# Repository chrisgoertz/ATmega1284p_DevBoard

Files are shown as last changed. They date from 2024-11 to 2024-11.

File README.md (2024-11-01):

# ATmega1284p_DevBoard
AVR Developement Board
## Features
### LCD Connector
Precofigured Header for standard Character Display pinouts.
### Buttons
8 on board push buttons. 4 with attached pull-up resistor, 4 with
attached pull-down resistor.
### FTDI Connector
Standard FTDI Connector with attachable DTR enable like Arduino. 
So it is possible to reset and programm the MCU via FTDI connection
if a bootloader is flashed and enabled.
### JTAG Connector
2 AVR JTAG Headers for programming and debugging.
### ISP
Standard 6-pin AVR ISP.
### Serial
6-pin connector with UART0 and UART1 and also VCC and GND.
### I²C
6-Pin Connector with SDA and SCL, VCC, GND and GPIO D7.
### LED-BARs
2 10-Channel LED-Bars, attached to PortA and PortC. 
Both channels can be separate enabled by jumper. Since all
LEDs are decoupled via MOSFETs, they don't affect the GPIOs.

## Pictures
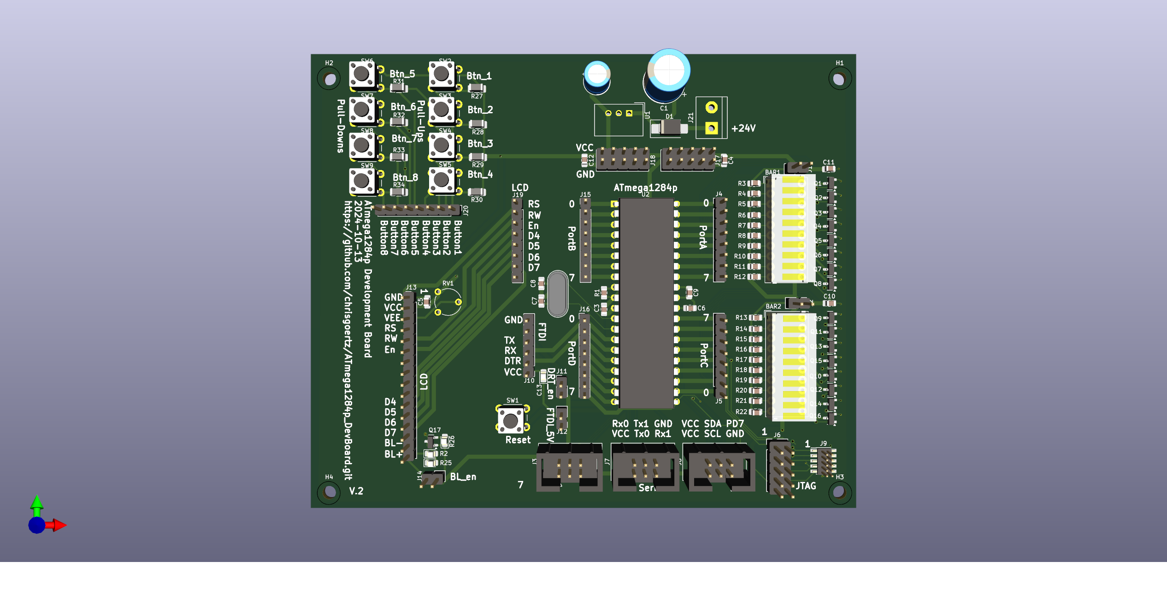
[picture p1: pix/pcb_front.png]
front view

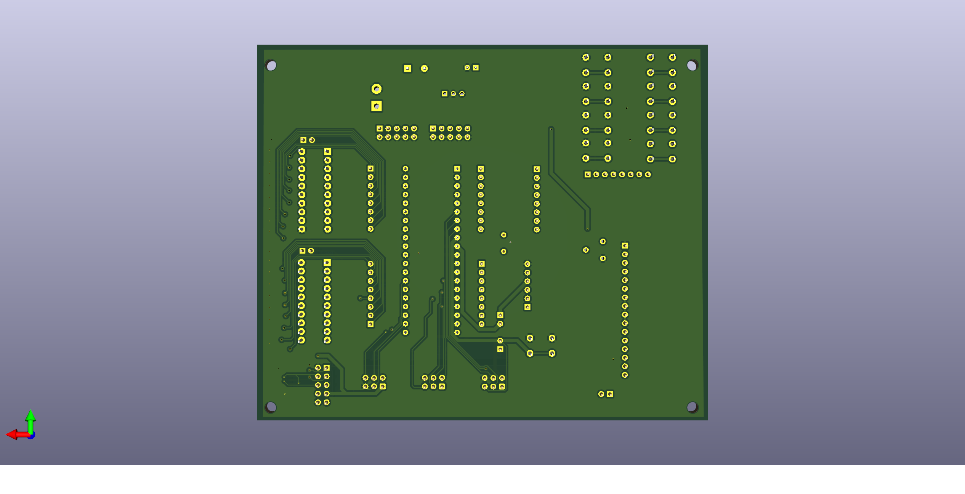
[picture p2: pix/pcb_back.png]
back view


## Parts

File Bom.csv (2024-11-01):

ID | Bezeichner | Footprint | Stückzahl | Bezeichnung | Anbieter und Referenz
1 | SW2,SW5,SW1,SW6,SW3,SW7,SW8,SW9,SW4 | SW_PUSH_6mm | 9 | SW_Push_Open_Dual
2 | J12 | PinHeader_1x02_P2.54mm_Vertical | 1 | FTDI_DTR_en
3 | Q7,Q8,Q2,Q1,Q4,Q11,Q14,Q16,Q6,Q13,Q12,Q9,Q5,Q10,Q17,Q3,Q15 | SOT-23 | 17 | 2N7002
4 | R24,R23 | L_1206_3216Metric_Pad1.42x1.75mm_HandSolder | 2 | 6K19
5 | R29,R32,R33,R34,R28,R31,R30,R27 | L_1206_3216Metric_Pad1.42x1.75mm_HandSolder | 8 | 9K53
6 | R11,R20,R21,R15,R17,R14,R10,R8,R18,R4,R7,R16,R9,R6,R19,R22,R3,R13,R5 | C_0805_2012Metric_Pad1.18x1.45mm_HandSolder | 19 | 330
7 | J17,J18 | PinHeader_2x05_P2.54mm_Vertical | 2 | Supply
8 | R1 | C_0805_2012Metric_Pad1.18x1.45mm_HandSolder | 1 | 11K3
9 | J20 | PinHeader_1x08_P2.54mm_Vertical | 1 | Buttons
10 | R26 | LED_0805_2012Metric_Pad1.15x1.40mm_HandSolder | 1 | 11K3
11 | BAR1,BAR2 | HDSP-4850 | 2 | HDSP-4850_2
12 | J21 | TerminalBlock_bornier-2_P5.08mm | 1 | Power Supply
13 | J9 | PinHeader_2x05_P1.27mm_Vertical_SMD | 1 | AVR-JTAG-10
14 | C11,C4,C9,C10,C3,C6,C12,C5 | C_0805_2012Metric_Pad1.18x1.45mm_HandSolder | 8 | 100nF
15 | C8,C7 | C_0805_2012Metric_Pad1.18x1.45mm_HandSolder | 2 | 22pF
16 | J5 | PinHeader_1x08_P2.54mm_Vertical | 1 | PORTC
17 | R25,R2 | LED_0805_2012Metric_Pad1.15x1.40mm_HandSolder | 2 | 100R
18 | J6 | PinHeader_2x05_P2.54mm_Vertical | 1 | AVR-JTAG-10
19 | C1 | CP_Radial_D10.0mm_P5.00mm | 1 | 470uF
20 | RV1 | Potentiometer_Piher_PT-6-V_Vertical | 1 | 10K
21 | J10 | PinHeader_1x06_P2.54mm_Vertical | 1 | FTDI
22 | J13 | PinHeader_1x16_P2.54mm_Vertical | 1 | LCD
23 | C13 | LED_0805_2012Metric_Pad1.15x1.40mm_HandSolder | 1 | 100nF
24 | J4 | PinHeader_1x08_P2.54mm_Vertical | 1 | PORTA
25 | C2 | CP_Radial_D6.3mm_P2.50mm | 1 | 220uF
26 | J19 | PinHeader_1x08_P2.54mm_Vertical | 1 | LCD_Interface
27 | J2 | PinHeader_1x02_P2.54mm_Vertical | 1 | PortB_LEDS_en
28 | U2 | DIP-40_W15.24mm | 1 | ATmega644-20P
29 | J3 | IDC-Header_2x03_P2.54mm_Vertical | 1 | AVR-ISP-6
30 | J7 | IDC-Header_2x03_P2.54mm_Vertical | 1 | Serial
31 | Y1 | Crystal_HC49-4H_Vertical | 1 | 20 MHz
32 | J8 | IDC-Header_2x03_P2.54mm_Vertical | 1 | I2C
33 | J14 | PinHeader_1x02_P2.54mm_Vertical | 1 | Conn_01x02
34 | U1 | Converter_DCDC_TRACO_TSR1-xxxxE_THT | 1 | TSR1-2450E
35 | J1 | PinHeader_1x02_P2.54mm_Vertical | 1 | PortA_LEDS_en
36 | D1 | D_SMB_Handsoldering | 1 | SMS140
37 | J15 | PinHeader_1x08_P2.54mm_Vertical | 1 | PORTB
38 | R12 | C_0805_2012Metric_Pad1.18x1.45mm_HandSolder | 1 | 930
39 | J11 | PinHeader_1x02_P2.54mm_Vertical | 1 | FTDI_VCC_en
40 | J16 | PinHeader_1x08_P2.54mm_Vertical | 1 | PORTD

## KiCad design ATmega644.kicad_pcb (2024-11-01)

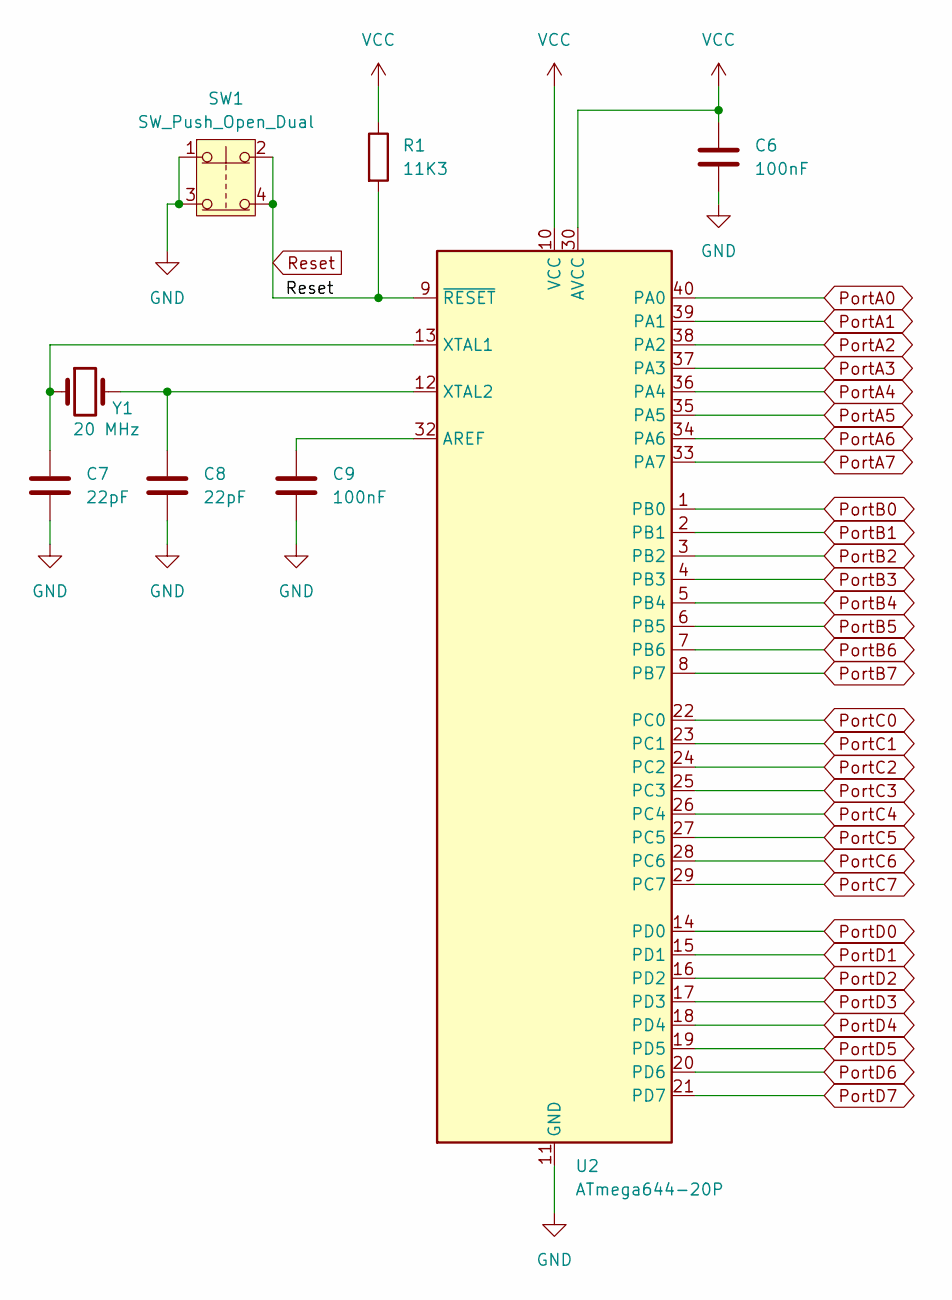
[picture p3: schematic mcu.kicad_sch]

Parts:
C6, C9: 100nF; C_0805_2012Metric_Pad1.18x1.45mm_HandSolder
C7, C8: 22pF; C_0805_2012Metric_Pad1.18x1.45mm_HandSolder
R1: 11K3; C_0805_2012Metric_Pad1.18x1.45mm_HandSolder
SW1: SW_Push_Open_Dual; SW_PUSH_6mm
U2: ATmega644-20P; DIP-40_W15.24mm
Y1: 20 MHz; Crystal_HC49-4H_Vertical

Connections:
GND: C6.2, C7.2, C8.2, C9.2, SW1.1, SW1.3, U2.11 (GND), U2.31 (GND); also elsewhere on the board
unnamed: C9.1, U2.32 (AREF)
unnamed: C7.1, U2.13 (XTAL1), Y1.1
unnamed: C8.1, U2.12 (XTAL2), Y1.2
PortA0: U2.40 (PA0); also elsewhere on the board
PortA1: U2.39 (PA1); also elsewhere on the board
PortA2: U2.38 (PA2); also elsewhere on the board
PortA3: U2.37 (PA3); also elsewhere on the board
PortA4: U2.36 (PA4); also elsewhere on the board
PortA5: U2.35 (PA5); also elsewhere on the board
PortA6: U2.34 (PA6); also elsewhere on the board
PortA7: U2.33 (PA7); also elsewhere on the board
PortB0: U2.1 (PB0); also elsewhere on the board
PortB1: U2.2 (PB1); also elsewhere on the board
PortB2: U2.3 (PB2); also elsewhere on the board
PortB3: U2.4 (PB3); also elsewhere on the board
PortB4: U2.5 (PB4); also elsewhere on the board
PortB5: U2.6 (PB5); also elsewhere on the board
PortB6: U2.7 (PB6); also elsewhere on the board
PortB7: U2.8 (PB7); also elsewhere on the board
PortC0: U2.22 (PC0); also elsewhere on the board
PortC1: U2.23 (PC1); also elsewhere on the board
PortC2: U2.24 (PC2); also elsewhere on the board
PortC3: U2.25 (PC3); also elsewhere on the board
PortC4: U2.26 (PC4); also elsewhere on the board
PortC5: U2.27 (PC5); also elsewhere on the board
PortC6: U2.28 (PC6); also elsewhere on the board
PortC7: U2.29 (PC7); also elsewhere on the board
PortD0: U2.14 (PD0); also elsewhere on the board
PortD1: U2.15 (PD1); also elsewhere on the board
PortD2: U2.16 (PD2); also elsewhere on the board
PortD3: U2.17 (PD3); also elsewhere on the board
PortD4: U2.18 (PD4); also elsewhere on the board
PortD5: U2.19 (PD5); also elsewhere on the board
PortD6: U2.20 (PD6); also elsewhere on the board
PortD7: U2.21 (PD7); also elsewhere on the board
Reset: R1.2, SW1.2, SW1.4, U2.9 (~RESET); also elsewhere on the board
VCC: C6.1, R1.1, U2.10 (VCC), U2.30 (AVCC); also elsewhere on the board

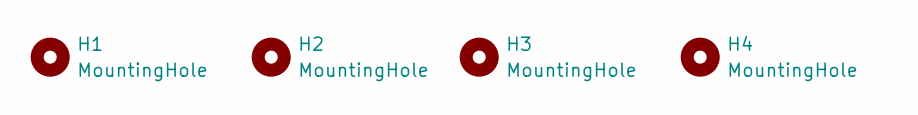
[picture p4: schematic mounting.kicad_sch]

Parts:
H1, H2, H3, H4: MountingHole; MountingHole_3.2mm_M3_DIN965

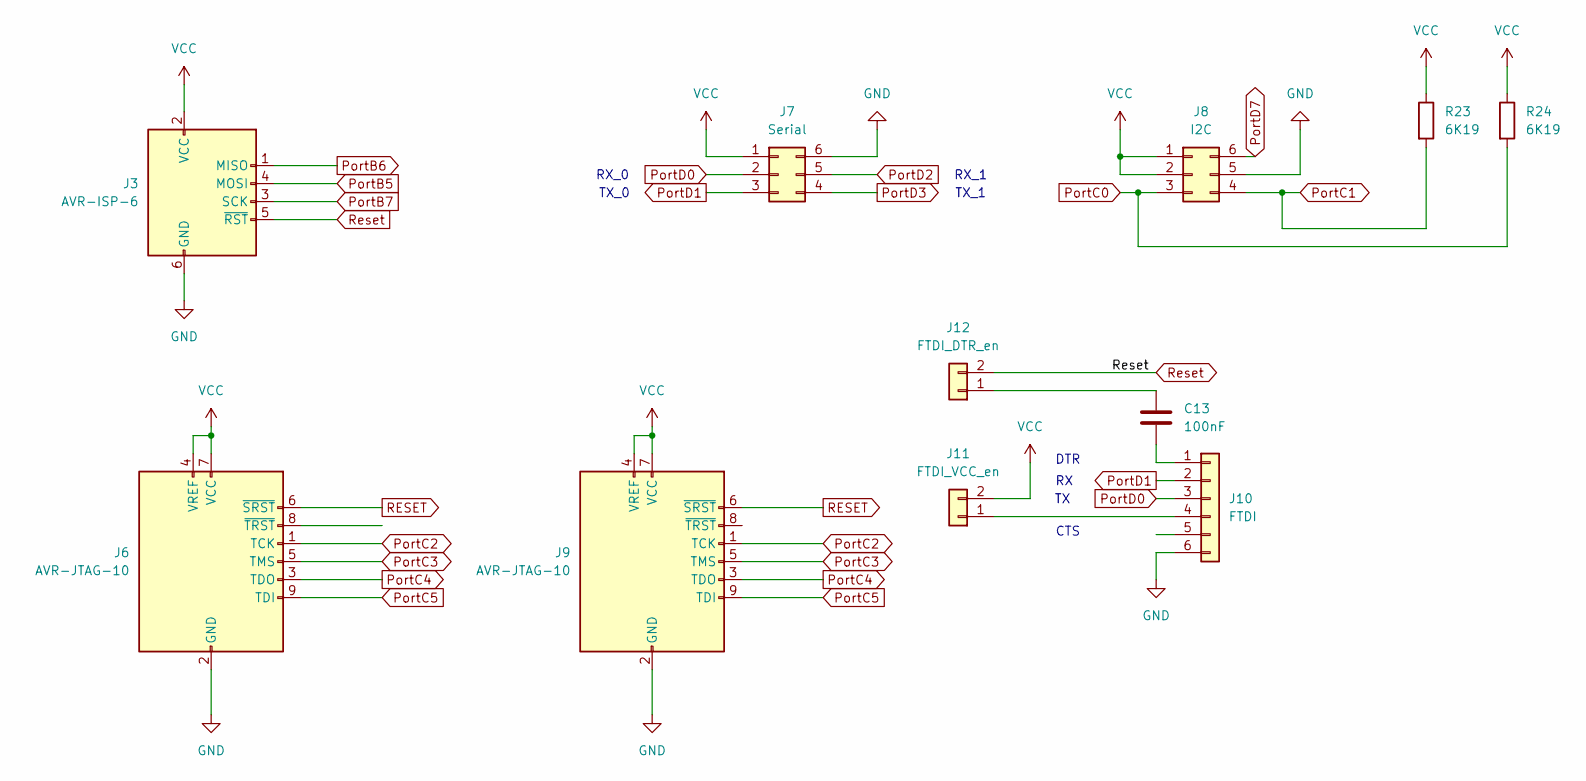
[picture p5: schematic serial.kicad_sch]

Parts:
C13: 100nF; LED_0805_2012Metric_Pad1.15x1.40mm_HandSolder
J3: AVR-ISP-6; IDC-Header_2x03_P2.54mm_Vertical
J6: AVR-JTAG-10; PinHeader_2x05_P2.54mm_Vertical
J7: Serial; IDC-Header_2x03_P2.54mm_Vertical
J8: I2C; IDC-Header_2x03_P2.54mm_Vertical
J9: AVR-JTAG-10; PinHeader_2x05_P1.27mm_Vertical_SMD
J10: FTDI; PinHeader_1x06_P2.54mm_Vertical
J11: FTDI_VCC_en; PinHeader_1x02_P2.54mm_Vertical
J12: FTDI_DTR_en; PinHeader_1x02_P2.54mm_Vertical
R23, R24: 6K19; L_1206_3216Metric_Pad1.42x1.75mm_HandSolder

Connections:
GND: J3.6 (GND), J6.2 (GND), J6.10 (GND), J7.6, J8.5, J9.2 (GND), J9.10 (GND), J10.6; also elsewhere on the board
unnamed: C13.2, J10.1
unnamed: J10.4, J11.1
unnamed: C13.1, J12.1
PortB5: J3.4 (MOSI); also elsewhere on the board
PortB6: J3.1 (MISO); also elsewhere on the board
PortB7: J3.3 (SCK); also elsewhere on the board
PortC0: J8.3, R24.2; also elsewhere on the board
PortC1: J8.4, R23.2; also elsewhere on the board
PortC2: J6.1 (TCK), J9.1 (TCK); also elsewhere on the board
PortC3: J6.5 (TMS), J9.5 (TMS); also elsewhere on the board
PortC4: J6.3 (TDO), J9.3 (TDO); also elsewhere on the board
PortC5: J6.9 (TDI), J9.9 (TDI); also elsewhere on the board
PortD0: J7.2, J10.3; also elsewhere on the board
PortD1: J7.3, J10.2; also elsewhere on the board
PortD2: J7.5; also elsewhere on the board
PortD3: J7.4; also elsewhere on the board
PortD7: J8.6; also elsewhere on the board
RESET: J6.6 (~SRST), J9.6 (~SRST)
Reset: J3.5 (~RST), J12.2; also elsewhere on the board
VCC: J3.2 (VCC), J6.4 (VREF), J6.7 (VCC), J7.1, J8.1, J8.2, J9.4 (VREF), J9.7 (VCC), J11.2, R23.1, R24.1; also elsewhere on the board

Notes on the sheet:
TX_0
TX_1
CTS
RX_0
DTR
RX_1

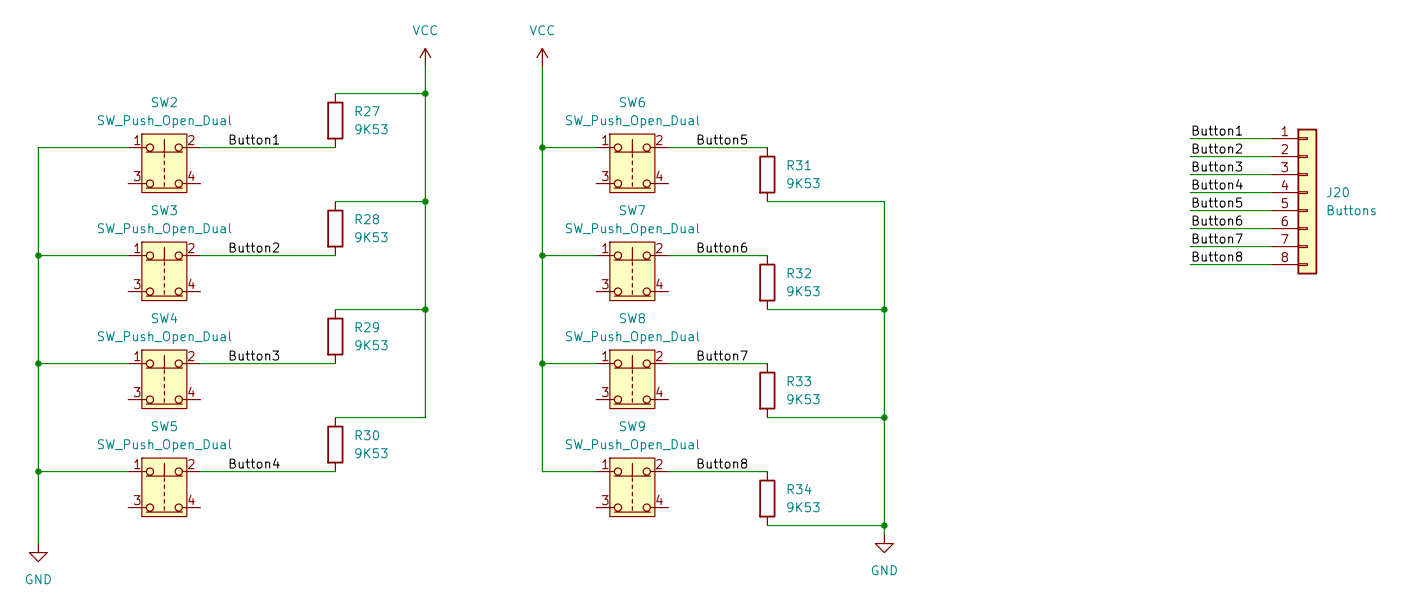
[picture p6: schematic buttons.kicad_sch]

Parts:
J20: Buttons; PinHeader_1x08_P2.54mm_Vertical
R27, R28, R29, R30, R31, R32, R33, R34: 9K53; L_1206_3216Metric_Pad1.42x1.75mm_HandSolder
SW2, SW3, SW4, SW5, SW6, SW7, SW8, SW9: SW_Push_Open_Dual; SW_PUSH_6mm

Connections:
/Buttons/Button1: J20.1, R27.2, SW2.2
/Buttons/Button2: J20.2, R28.2, SW3.2
/Buttons/Button3: J20.3, R29.2, SW4.2
/Buttons/Button4: J20.4, R30.2, SW5.2
/Buttons/Button5: J20.5, R31.1, SW6.2
/Buttons/Button6: J20.6, R32.1, SW7.2
/Buttons/Button7: J20.7, R33.1, SW8.2
/Buttons/Button8: J20.8, R34.1, SW9.2
GND: R31.2, R32.2, R33.2, R34.2, SW2.1, SW3.1, SW4.1, SW5.1; also elsewhere on the board
VCC: R27.1, R28.1, R29.1, R30.1, SW6.1, SW7.1, SW8.1, SW9.1; also elsewhere on the board

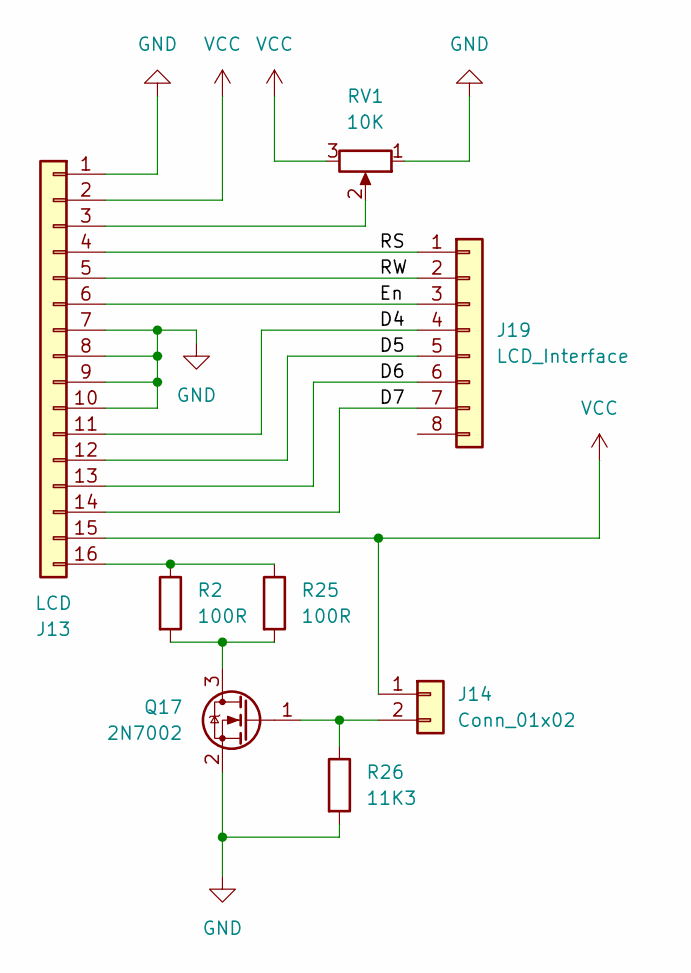
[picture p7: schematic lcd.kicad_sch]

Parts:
J13: LCD; PinHeader_1x16_P2.54mm_Vertical
J14: Conn_01x02; PinHeader_1x02_P2.54mm_Vertical
J19: LCD_Interface; PinHeader_1x08_P2.54mm_Vertical
Q17: 2N7002; SOT-23
R2, R25: 100R; LED_0805_2012Metric_Pad1.15x1.40mm_HandSolder
R26: 11K3; LED_0805_2012Metric_Pad1.15x1.40mm_HandSolder
RV1: 10K; Potentiometer_Piher_PT-6-V_Vertical

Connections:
/LCD/D4: J13.11, J19.4
/LCD/D5: J13.12, J19.5
/LCD/D6: J13.13, J19.6
/LCD/D7: J13.14, J19.7
/LCD/En: J13.6, J19.3
/LCD/RS: J13.4, J19.1
/LCD/RW: J13.5, J19.2
GND: J13.1, J13.7, J13.8, J13.9, J13.10, Q17.2 (S), R26.2, RV1.1; also elsewhere on the board
unnamed: J13.3, RV1.2
unnamed: J13.16, R2.1, R25.1
unnamed: J14.2, Q17.1 (G), R26.1
unnamed: Q17.3 (D), R2.2, R25.2
VCC: J13.2, J13.15, J14.1, RV1.3; also elsewhere on the board

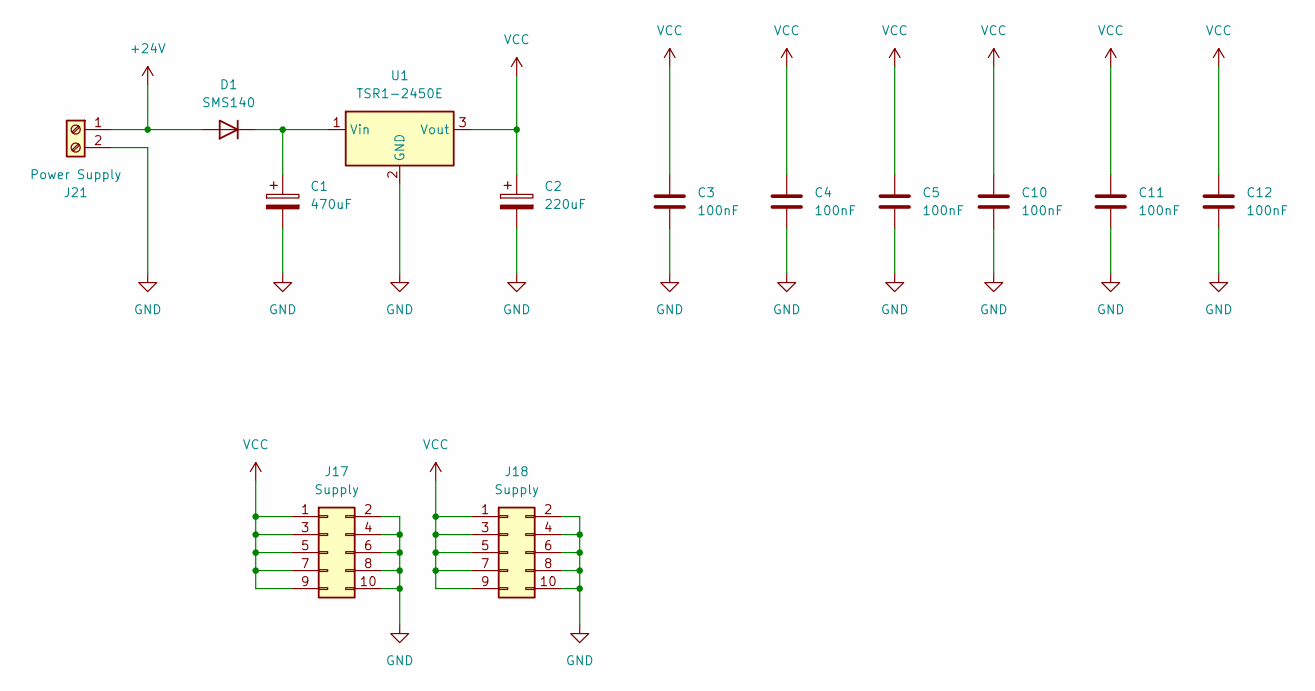
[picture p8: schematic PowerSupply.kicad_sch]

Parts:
C1: 470uF; CP_Radial_D10.0mm_P5.00mm
C2: 220uF; CP_Radial_D6.3mm_P2.50mm
C3, C4, C5, C10, C11, C12: 100nF; C_0805_2012Metric_Pad1.18x1.45mm_HandSolder
D1: SMS140; D_SMB_Handsoldering
J17, J18: Supply; PinHeader_2x05_P2.54mm_Vertical
J21: Power Supply; TerminalBlock_bornier-2_P5.08mm
U1: TSR1-2450E; Converter_DCDC_TRACO_TSR1-xxxxE_THT

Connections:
+24V: D1.2 (A), J21.1
GND: C1.2, C2.2, C3.2, C4.2, C5.2, C10.2, C11.2, C12.2, J17.2, J17.4, J17.6, J17.8, J17.10, J18.2, J18.4, J18.6, J18.8, J18.10, J21.2, U1.2 (GND); also elsewhere on the board
unnamed: C1.1, D1.1 (K), U1.1 (Vin)
VCC: C2.1, C3.1, C4.1, C5.1, C10.1, C11.1, C12.1, J17.1, J17.3, J17.5, J17.7, J17.9, J18.1, J18.3, J18.5, J18.7, J18.9, U1.3 (Vout); also elsewhere on the board

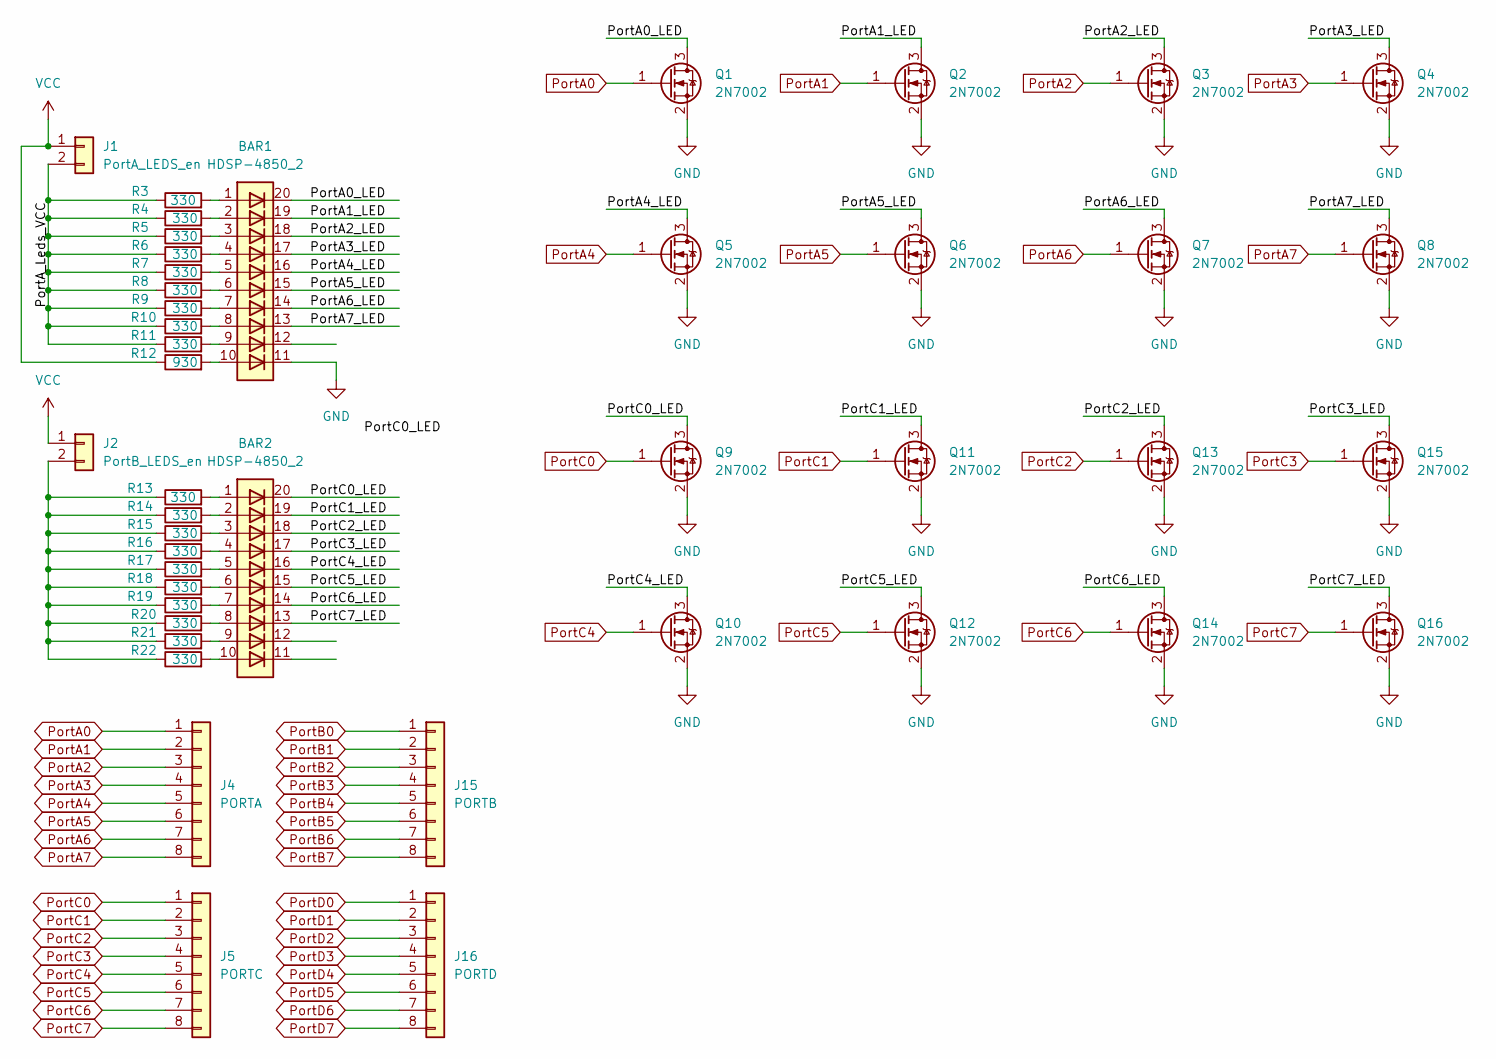
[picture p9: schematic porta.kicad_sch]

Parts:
BAR1, BAR2: HDSP-4850_2; HDSP-4850
J1: PortA_LEDS_en; PinHeader_1x02_P2.54mm_Vertical
J2: PortB_LEDS_en; PinHeader_1x02_P2.54mm_Vertical
J4: PORTA; PinHeader_1x08_P2.54mm_Vertical
J5: PORTC; PinHeader_1x08_P2.54mm_Vertical
J15: PORTB; PinHeader_1x08_P2.54mm_Vertical
J16: PORTD; PinHeader_1x08_P2.54mm_Vertical
Q1, Q2, Q3, Q4, Q5, Q6, Q7, Q8, Q9, Q10, Q11, Q12, Q13, Q14, Q15, Q16: 2N7002; SOT-23
R3, R4, R5, R6, R7, R8, R9, R10, R11, R13, R14, R15, R16, R17, R18, R19, R20, R21, R22: 330; C_0805_2012Metric_Pad1.18x1.45mm_HandSolder
R12: 930; C_0805_2012Metric_Pad1.18x1.45mm_HandSolder

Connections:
/PORTS/PortA0_LED: BAR1.20 (K), Q1.3 (D)
/PORTS/PortA1_LED: BAR1.19 (K), Q2.3 (D)
/PORTS/PortA2_LED: BAR1.18 (K), Q3.3 (D)
/PORTS/PortA3_LED: BAR1.17 (K), Q4.3 (D)
/PORTS/PortA4_LED: BAR1.16 (K), Q5.3 (D)
/PORTS/PortA5_LED: BAR1.15 (K), Q6.3 (D)
/PORTS/PortA6_LED: BAR1.14 (K), Q7.3 (D)
/PORTS/PortA7_LED: BAR1.13 (K), Q8.3 (D)
/PORTS/PortA_Leds_VCC: J1.2, R3.1, R4.1, R5.1, R6.1, R7.1, R8.1, R9.1, R10.1, R11.1
/PORTS/PortC0_LED: BAR2.20 (K), Q9.3 (D)
/PORTS/PortC1_LED: BAR2.19 (K), Q11.3 (D)
/PORTS/PortC2_LED: BAR2.18 (K), Q13.3 (D)
/PORTS/PortC3_LED: BAR2.17 (K), Q15.3 (D)
/PORTS/PortC4_LED: BAR2.16 (K), Q10.3 (D)
/PORTS/PortC5_LED: BAR2.15 (K), Q12.3 (D)
/PORTS/PortC6_LED: BAR2.14 (K), Q14.3 (D)
/PORTS/PortC7_LED: BAR2.13 (K), Q16.3 (D)
GND: BAR1.11 (K), Q1.2 (S), Q2.2 (S), Q3.2 (S), Q4.2 (S), Q5.2 (S), Q6.2 (S), Q7.2 (S), Q8.2 (S), Q9.2 (S), Q10.2 (S), Q11.2 (S), Q12.2 (S), Q13.2 (S), Q14.2 (S), Q15.2 (S), Q16.2 (S); also elsewhere on the board
unnamed: BAR1.1 (A), R3.2
unnamed: BAR1.2 (A), R4.2
unnamed: BAR1.3 (A), R5.2
unnamed: BAR1.4 (A), R6.2
unnamed: BAR1.5 (A), R7.2
unnamed: BAR1.6 (A), R8.2
unnamed: BAR1.7 (A), R9.2
unnamed: BAR1.8 (A), R10.2
unnamed: BAR1.9 (A), R11.2
unnamed: BAR1.10 (A), R12.2
unnamed: BAR2.1 (A), R13.2
unnamed: BAR2.2 (A), R14.2
unnamed: BAR2.3 (A), R15.2
unnamed: BAR2.4 (A), R16.2
unnamed: BAR2.5 (A), R17.2
unnamed: BAR2.6 (A), R18.2
unnamed: BAR2.7 (A), R19.2
unnamed: BAR2.8 (A), R20.2
unnamed: BAR2.9 (A), R21.2
unnamed: BAR2.10 (A), R22.2
unnamed: J2.2, R13.1, R14.1, R15.1, R16.1, R17.1, R18.1, R19.1, R20.1, R21.1, R22.1
PortA0: J4.1, Q1.1 (G); also elsewhere on the board
PortA1: J4.2, Q2.1 (G); also elsewhere on the board
PortA2: J4.3, Q3.1 (G); also elsewhere on the board
PortA3: J4.4, Q4.1 (G); also elsewhere on the board
PortA4: J4.5, Q5.1 (G); also elsewhere on the board
PortA5: J4.6, Q6.1 (G); also elsewhere on the board
PortA6: J4.7, Q7.1 (G); also elsewhere on the board
PortA7: J4.8, Q8.1 (G); also elsewhere on the board
PortB0: J15.1; also elsewhere on the board
PortB1: J15.2; also elsewhere on the board
PortB2: J15.3; also elsewhere on the board
PortB3: J15.4; also elsewhere on the board
PortB4: J15.5; also elsewhere on the board
PortB5: J15.6; also elsewhere on the board
PortB6: J15.7; also elsewhere on the board
PortB7: J15.8; also elsewhere on the board
PortC0: J5.1, Q9.1 (G); also elsewhere on the board
PortC1: J5.2, Q11.1 (G); also elsewhere on the board
PortC2: J5.3, Q13.1 (G); also elsewhere on the board
PortC3: J5.4, Q15.1 (G); also elsewhere on the board
PortC4: J5.5, Q10.1 (G); also elsewhere on the board
PortC5: J5.6, Q12.1 (G); also elsewhere on the board
PortC6: J5.7, Q14.1 (G); also elsewhere on the board
PortC7: J5.8, Q16.1 (G); also elsewhere on the board
PortD0: J16.1; also elsewhere on the board
PortD1: J16.2; also elsewhere on the board
PortD2: J16.3; also elsewhere on the board
PortD3: J16.4; also elsewhere on the board
PortD4: J16.5; also elsewhere on the board
PortD5: J16.6; also elsewhere on the board
PortD6: J16.7; also elsewhere on the board
PortD7: J16.8; also elsewhere on the board
VCC: J1.1, J2.1, R12.1; also elsewhere on the board

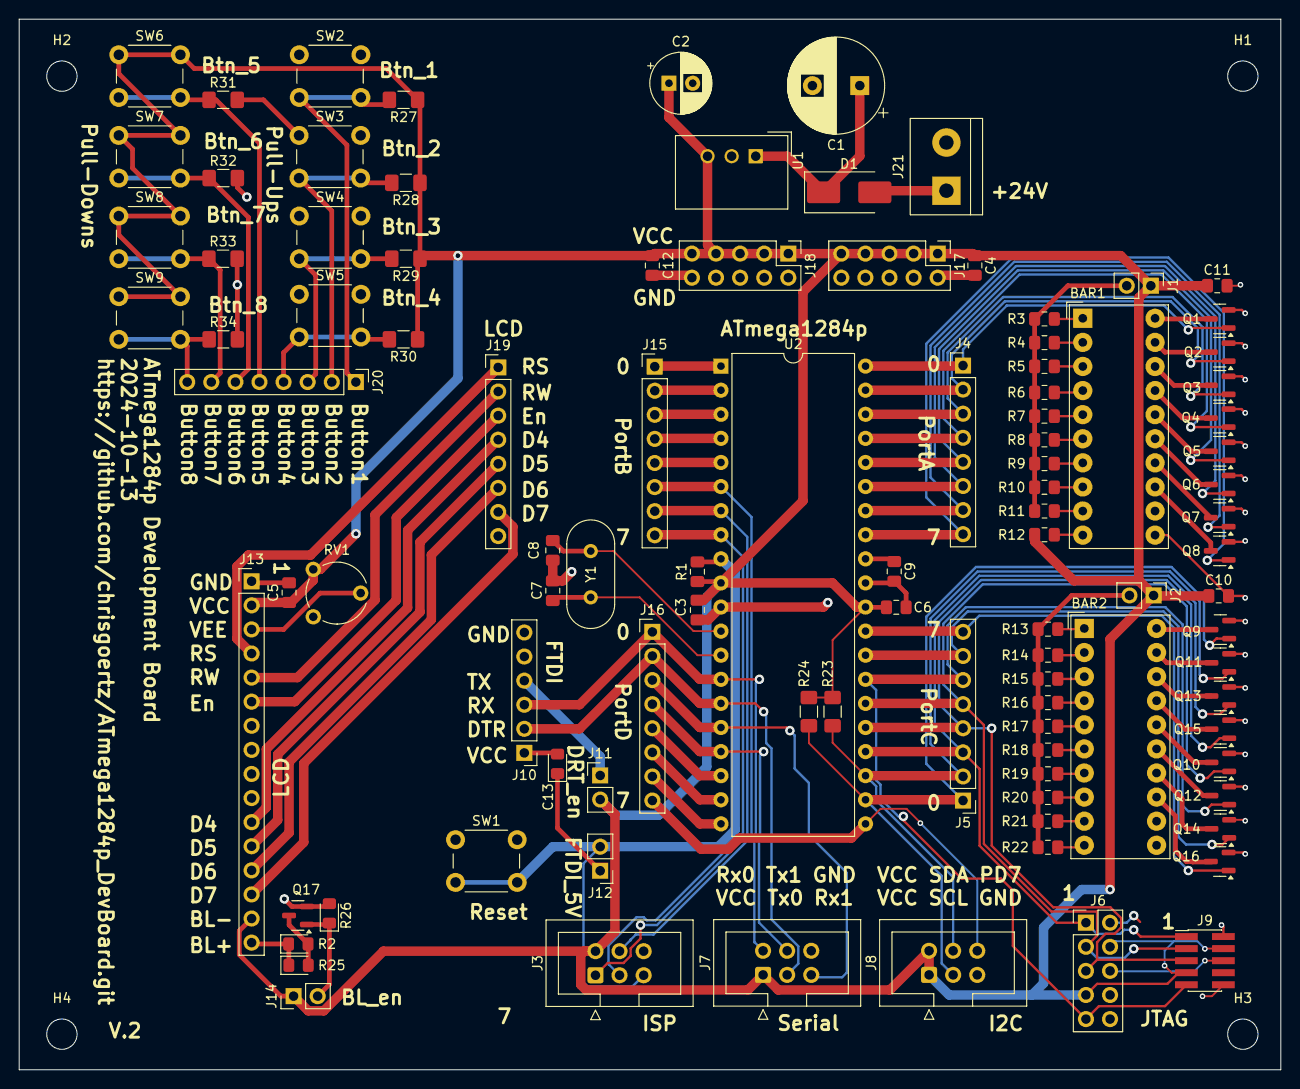
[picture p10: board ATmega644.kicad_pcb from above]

Board: 2 copper layers, 133.0 x 110.8 mm, 105 parts (0 on the bottom side), 101 nets.

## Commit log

2024-11-01 initial release
    [ATmega644.kicad_pcb, ATmega644.kicad_sch, PowerSupply.kicad_sch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]
2024-11-01 added bill of material
    [Bom.csv]
2024-11-01 added gerber files
    [ATmega644-B_Cu.gbr, ATmega644-B_Mask.gbr, ATmega644-B_Paste.gbr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]
2024-11-01 added pix
    [ATmega644.kicad_pcb]
